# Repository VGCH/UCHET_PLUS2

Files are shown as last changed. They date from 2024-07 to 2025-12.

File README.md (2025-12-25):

## Проект устройства для интеграции счетчиков воды в системы умного дома

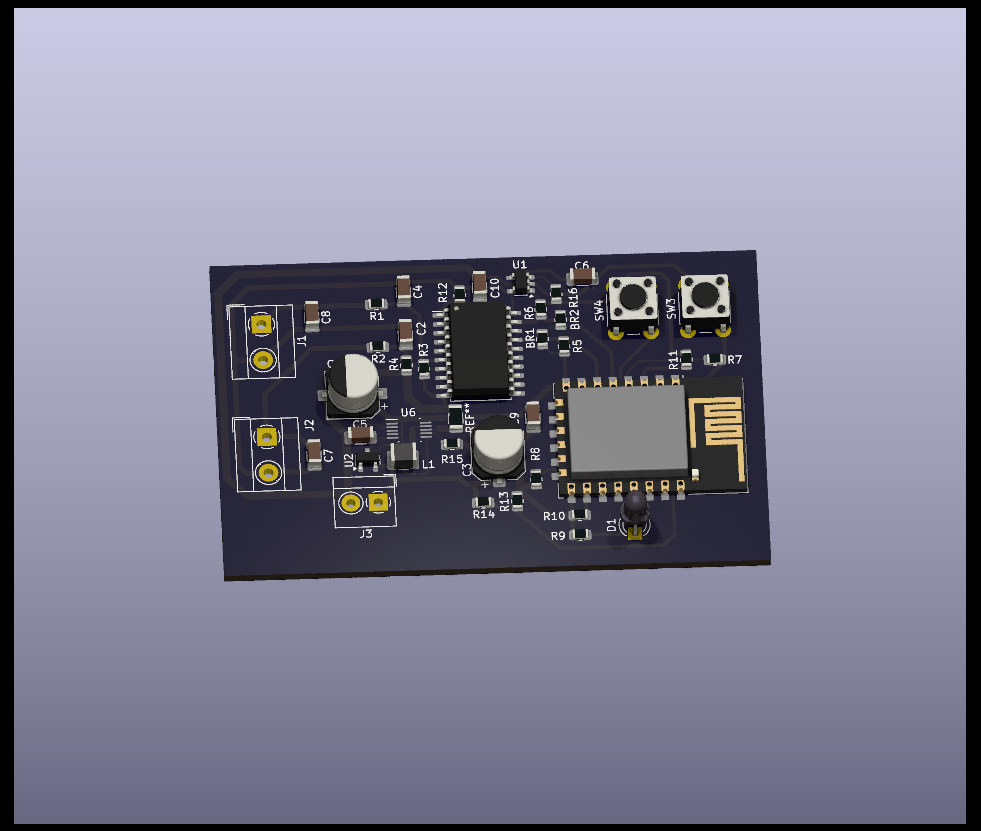
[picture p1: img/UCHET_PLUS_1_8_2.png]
Иллюстрация к проекту


Принципиальная схема

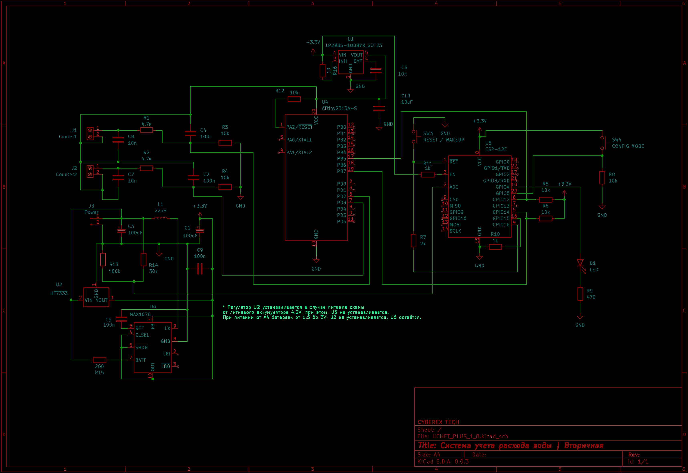
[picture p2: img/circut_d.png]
Принципиальная схема


Полное описание в статье на Хабр

[Ссылка на статью ](https://habr.com/ru/articles/827248/)

Если данный проект был вам полезен, то вы можете задонатить разработчику на оборудование. 

[Ссылка на донат](https://dalink.to/cyberex_tech)

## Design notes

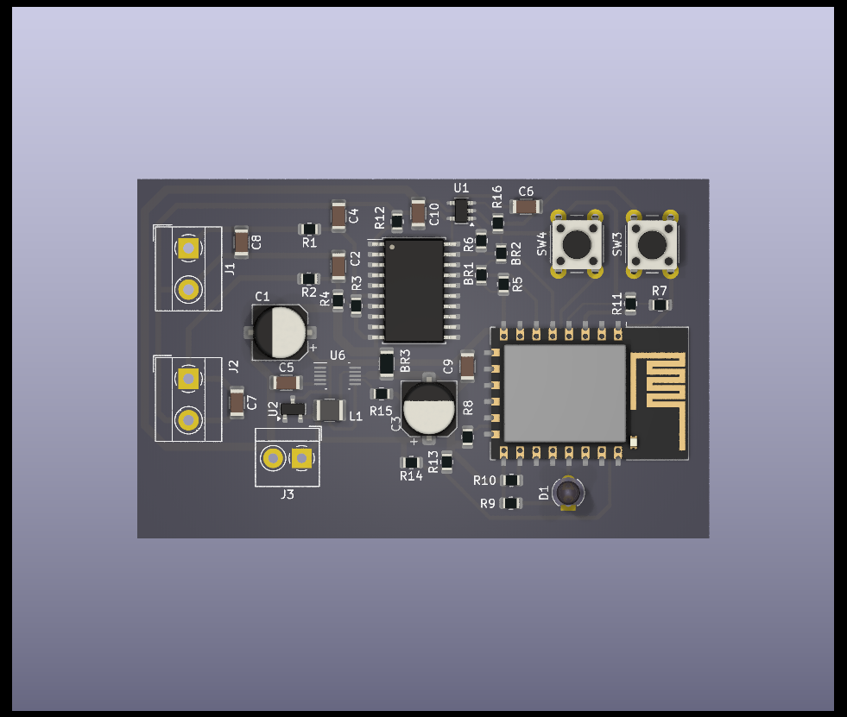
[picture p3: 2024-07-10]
img/UCHET_PLUS_1_8_3.png

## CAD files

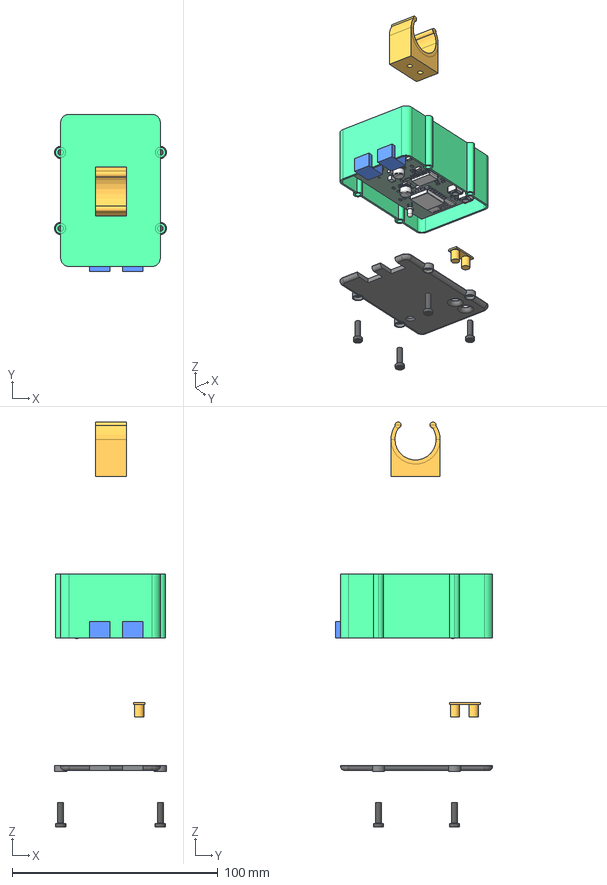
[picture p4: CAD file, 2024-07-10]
box/box_uchet_plus.FCStd
54.5 x 76.5 x 197.0 mm
Куб053
Куб054
SW_PUSH_6mm004
R_0805_2012Metric034
R_1206_3216Metric
R_0805_2012Metric036
R_0805_2012Metric038
LED_D3.0mm_IRGrey002
R_0805_2012Metric040
C_1206_3216Metric016
R_0805_2012Metric042
R_0805_2012Metric044
R_0805_2012Metric046
R_0805_2012Metric048
ESP_12E001_cp001
R_0805_2012Metric050
L_1210_3225Metric002
R_0805_2012Metric052
R_0805_2012Metric054
R_0805_2012Metric056
R_0805_2012Metric058
C_1206_3216Metric018
SOT_23_006
SW_PUSH_6mm006
C_1206_3216Metric020
CP_Elec_63x060
R_0805_2012Metric060
C_1206_3216Metric022
R_0805_2012Metric062
C_1206_3216Metric024
R_0805_2012Metric064
C_1206_3216Metric026
CP_Elec_63x061
C_1206_3216Metric028
SOIC_20W_75x128mm_P127mm001
R_0805_2012Metric066
C_1206_3216Metric030
R_0805_2012Metric068
UCHET_PLUS_1_8_PCB

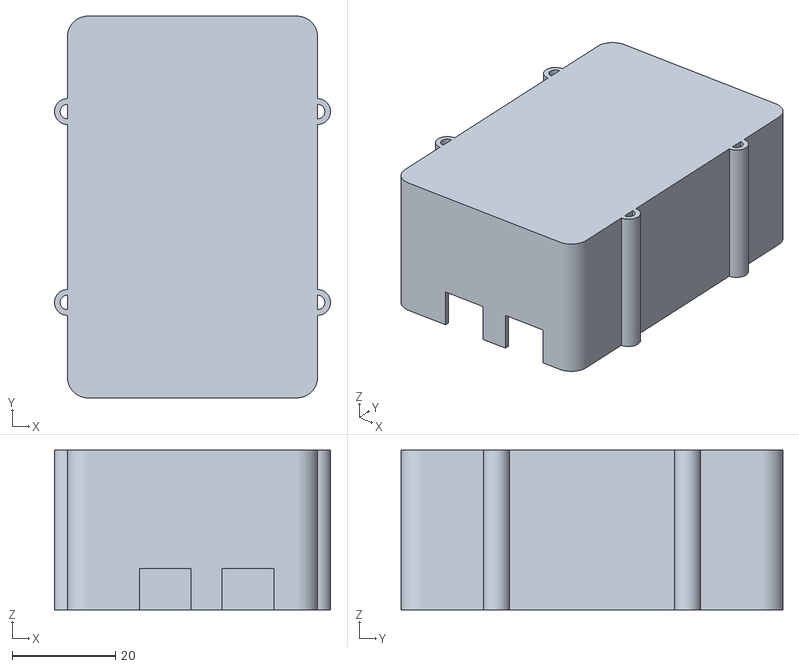
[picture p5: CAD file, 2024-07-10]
box/STL/box_uchet_plus-Cut043.stl
53.5 x 74.0 x 31.0

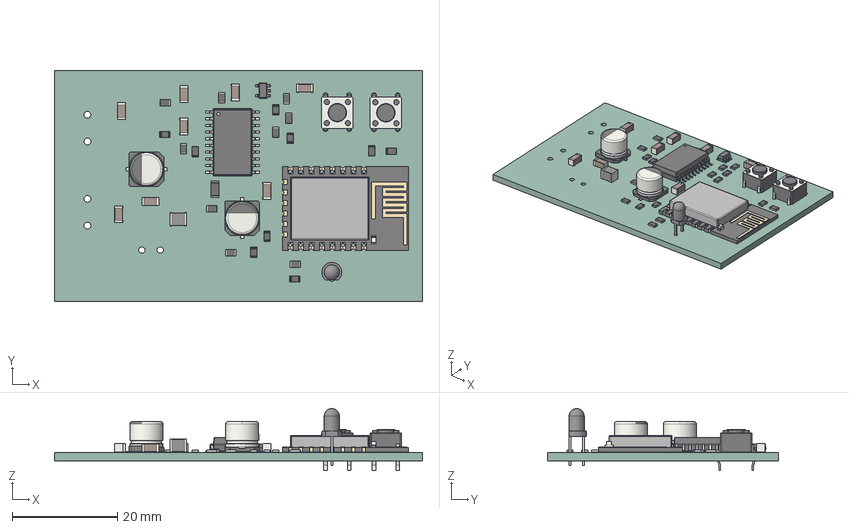
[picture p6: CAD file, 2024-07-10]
UCHET_PLUS_1_8/UCHET_PLUS_1_8.step
70.0 x 44.0 x 11.8 mm
SW_PUSH_6mm x 2
R_0805_2012Metric x 18
R_1206_3216Metric
LED_D3.0mm_IRGrey
C_1206_3216Metric x 8
ESP_12E001_cp
L_1210_3225Metric
SOT_23_5
CP_Elec_63x58 x 2
SOIC_20W_75x128mm_P127mm
UCHET_PLUS_1_8_PCB

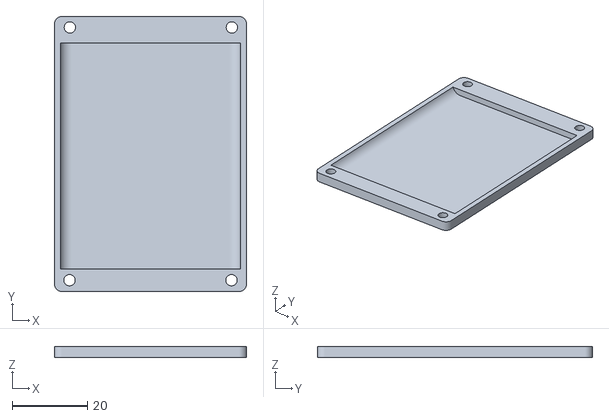
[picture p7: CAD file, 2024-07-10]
box/STL/box_uchet_plus_cup.stl
51.0 x 73.0 x 3.00

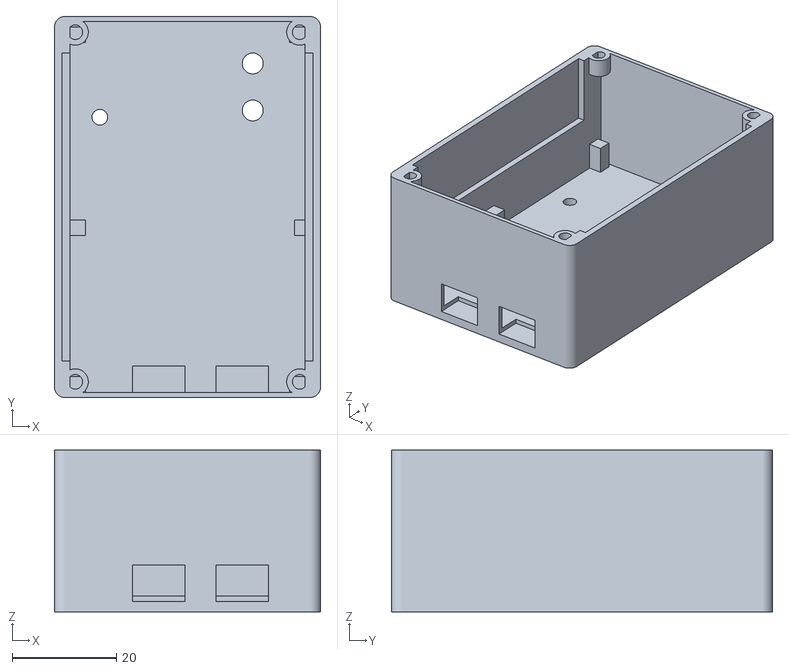
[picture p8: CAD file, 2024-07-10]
box/STL/box_uchet_plus-Cut008.stl
51.0 x 73.0 x 31.0

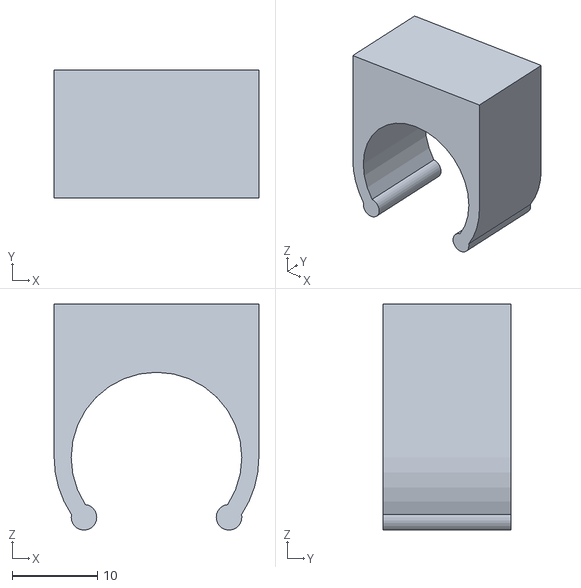
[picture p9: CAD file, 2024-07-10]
box/STL/box_uchet_plus_holder.stl
24.0 x 15.0 x 26.5

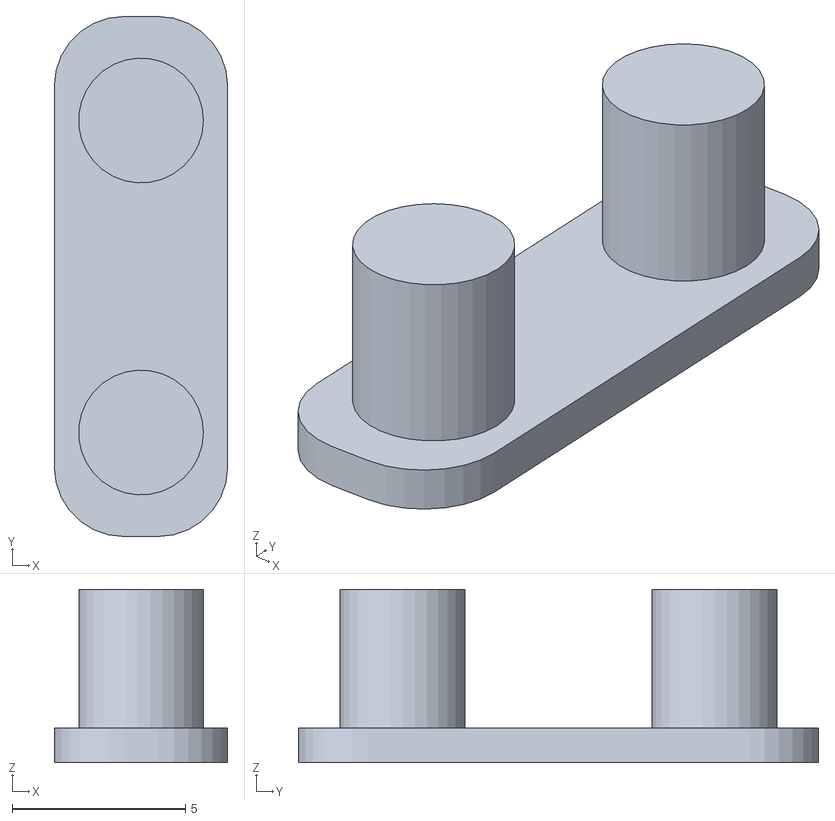
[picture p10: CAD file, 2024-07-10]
box/STL/box_uchet_but.stl
5.00 x 15.0 x 5.00

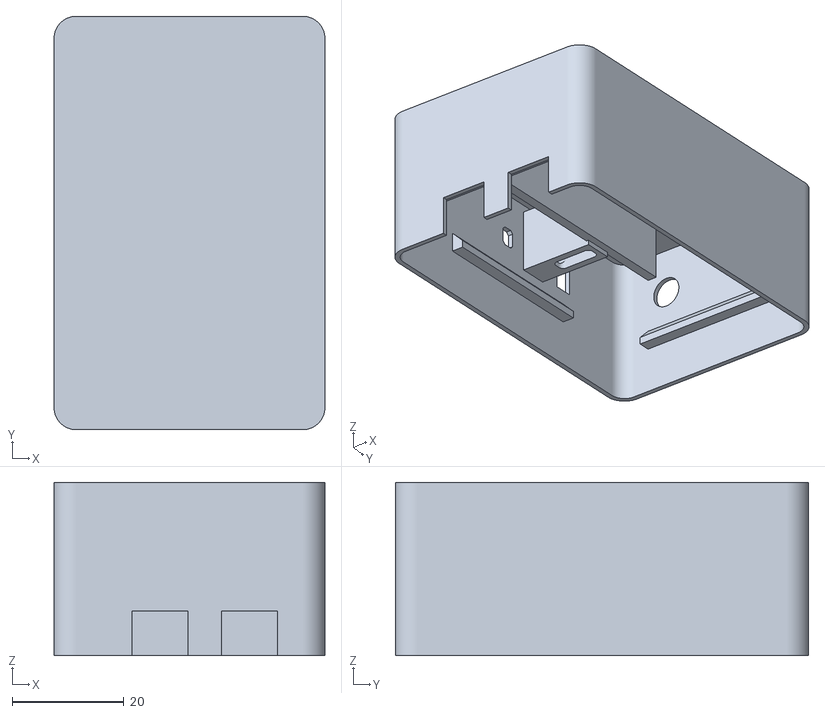
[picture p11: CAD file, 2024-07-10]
box/STL/box_uchet_plus-Fusion023.stl
48.5 x 74.0 x 31.0

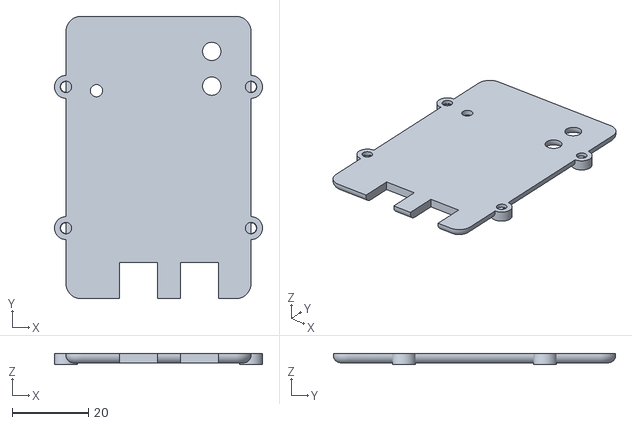
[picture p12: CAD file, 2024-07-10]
box/STL/box_uchet_plus-Cut042.stl
54.5 x 74.0 x 3.00

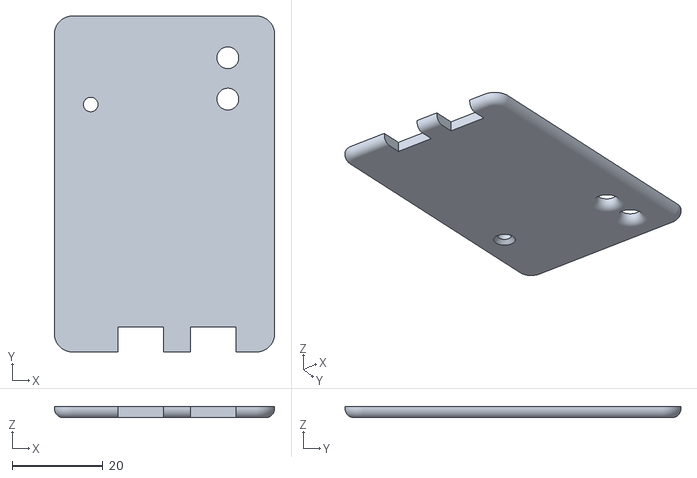
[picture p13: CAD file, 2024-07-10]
box/STL/box_uchet_plus-Cut040.stl
48.5 x 74.0 x 2.50

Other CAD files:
UCHET_PLUS_1_8/UCHET_PLUS_1_8_2.step
box/STL/box_uchet_plus-Cut044.stl
box/STL/box_uchet_plus.stl

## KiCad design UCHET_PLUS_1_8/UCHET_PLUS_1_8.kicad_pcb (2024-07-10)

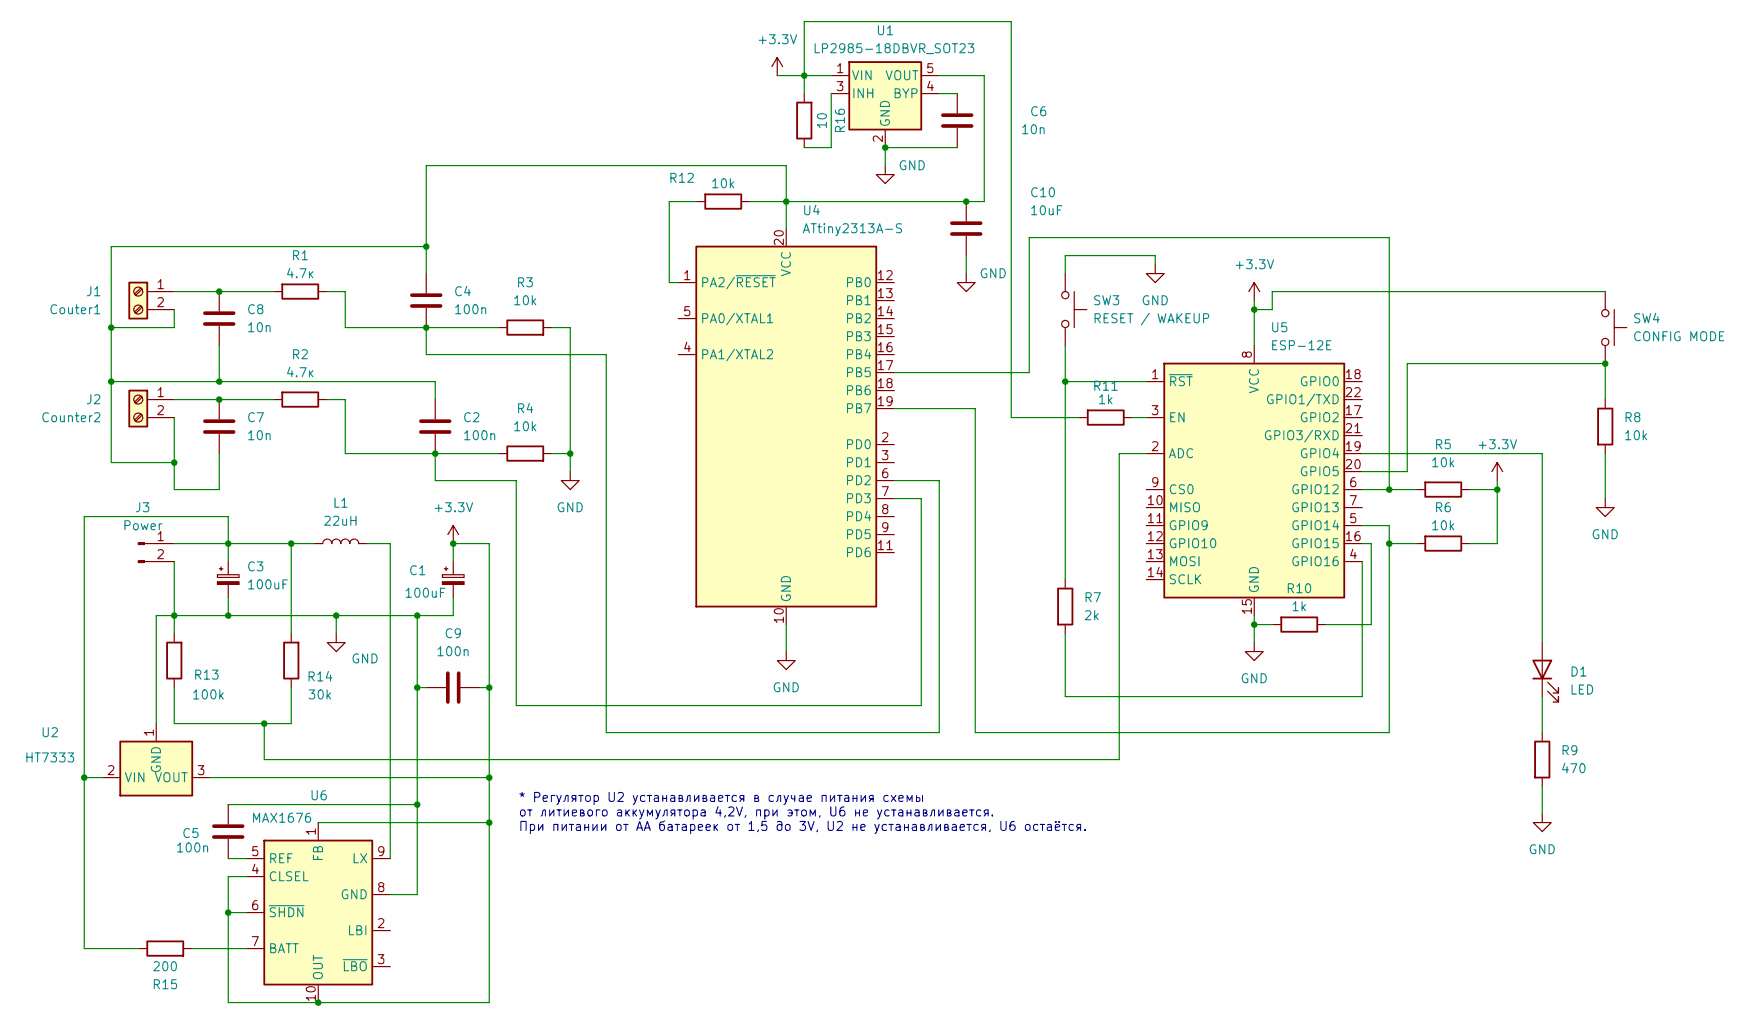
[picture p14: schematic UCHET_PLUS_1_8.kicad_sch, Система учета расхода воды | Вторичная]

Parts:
C1, C3: 100uF; CP_Elec_6.3x5.8
C2, C4, C5, C9: 100n; C_1206_3216Metric
C6, C7, C8: 10n; C_1206_3216Metric
C10: 10uF; C_1206_3216Metric
D1: LED; LED_D3.0mm_IRGrey
J1: Couter1; TerminalBlock_MetzConnect_Type101_RT01602HBWC_1x02_P5.08mm_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
J2: Counter2; TerminalBlock_MetzConnect_Type101_RT01602HBWC_1x02_P5.08mm_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
J3: Power; TerminalBlock_4Ucon_1x02_P3.50mm_Horizontal
L1: 22uH; L_1210_3225Metric
R1, R2: 4.7к; R_0805_2012Metric
R3, R4, R5, R6, R8, R12: 10k; R_0805_2012Metric
R7: 2k; R_0805_2012Metric
R9: 470; R_0805_2012Metric
R10, R11: 1k; R_0805_2012Metric
R13: 100k; R_0805_2012Metric
R14: 30k; R_0805_2012Metric
R15: 200; R_0805_2012Metric
R16: 10; R_0805_2012Metric
SW3: RESET / WAKEUP; SW_PUSH_6mm
SW4: CONFIG MODE; SW_PUSH_6mm
U1: LP2985-18DBVR_SOT23; SOT-23-5
U2: HT7333; SOT-23
U4: ATtiny2313A-S; SOIC-20W_7.5x12.8mm_P1.27mm
U5: ESP-12E
U6: MAX1676; MSOP-10-1EP_3x3mm_P0.5mm_EP2.2x3.1mm_Mask1.83x1.89mm_Therma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

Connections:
+3.3V: C1.1, C9.1, R5.1, R6.1, R11.2, R16.2, SW4.1, U1.1 (VIN), U2.3 (VOUT), U5.8 (VCC), U6.1 (FB), U6.4 (CLSEL), U6.6 (~SHDN), U6.10 (OUT), U6.11 (GND); also elsewhere on the board
GND: C1.2, C3.2, C5.1, C6.2, C9.2, C10.2, J3.2, R3.2, R4.2, R8.2, R9.2, R10.2, R13.2, SW3.1, U1.2 (GND), U2.1 (GND), U4.10 (GND), U5.15 (GND), U6.8 (GND); also elsewhere on the board
unnamed: D1.2 (A), U5.19 (GPIO4)
unnamed: D1.1 (K), R9.1
unnamed: C8.1, J1.1, R1.2
unnamed: C2.1, C4.1, C7.2, C8.2, C10.1, J1.2, J2.2, R12.1, U1.5 (VOUT), U4.20 (VCC)
unnamed: C7.1, J2.1, R2.2
unnamed: C3.1, J3.1, L1.1, R14.2, R15.1, U2.2 (VIN)
unnamed: C6.1, U1.4 (BYP)
unnamed: R16.1, U1.3 (INH)
unnamed: R12.2, U4.1 (PA2/~RESET)
unnamed: R5.2, U4.17 (PB5), U5.6 (GPIO12)
unnamed: R6.2, U4.19 (PB7), U5.5 (GPIO14)
unnamed: C4.2, R1.1, R3.1, U4.6 (PD2)
unnamed: C2.2, R2.1, R4.1, U4.7 (PD3)
unnamed: R13.1, R14.1, U5.2 (ADC)
unnamed: R11.1, U5.3 (EN)
unnamed: R8.1, SW4.2, U5.20 (GPIO5)
unnamed: R10.1, U5.16 (GPIO15)
unnamed: R7.2, U5.4 (GPIO16)
unnamed: R7.1, SW3.2, U5.1 (~RST)
unnamed: R15.2, U6.7 (BATT)
unnamed: L1.2, U6.9 (LX)
unnamed: C5.2, U6.5 (REF)

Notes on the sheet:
* Регулятор U2 устанавливается в случае питания схемы от литиевого аккумулятора 4,2V, при этом, U6 не устанавливается. При питании от AA батареек от 1,5 до 3V, U2 не устанавливается, U6 остаётся.

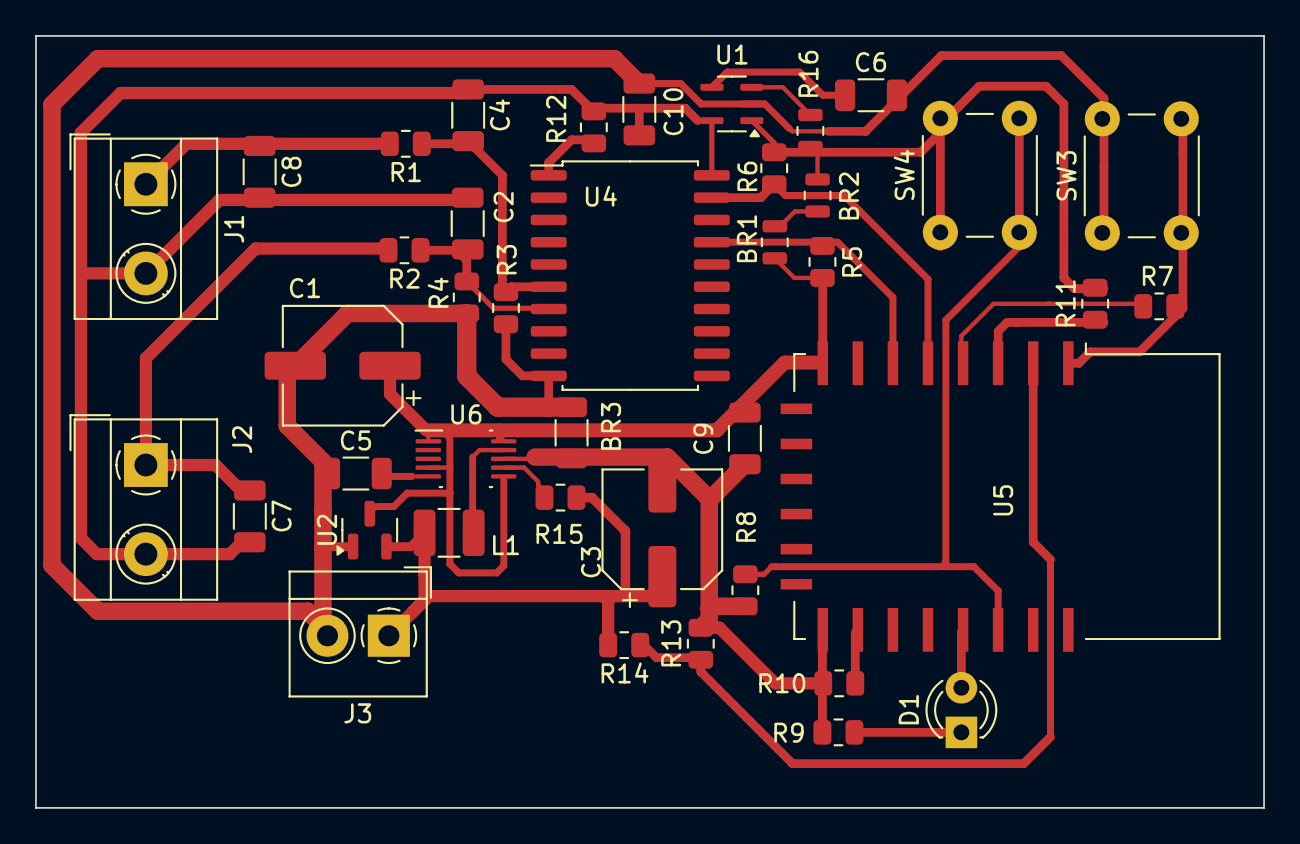
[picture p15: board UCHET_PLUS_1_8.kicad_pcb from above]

Board: 2 copper layers, 70.0 x 44.0 mm, 41 parts (0 on the bottom side), 24 nets.

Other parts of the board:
BR1, BR2: R_0805_2012Metric
BR3: R_1206_3216Metric

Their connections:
+3.3V: BR1.1, BR1.2, BR2.1, BR2.2; also elsewhere on the board
GND: BR3.1, BR3.2; also elsewhere on the board

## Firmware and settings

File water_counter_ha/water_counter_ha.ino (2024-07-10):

/* Устройство для получения данных с водосчетчиков с батарейным питанием
 *  
 *  © CYBEREX Tech, 2023
 * 
 */

#include <ESP8266WiFi.h>
#include <WiFiClient.h>
#include <ESP8266WebServer.h>
#include <ESP8266HTTPUpdateServer.h>
#include <DNSServer.h>
#include <ESP8266mDNS.h>
#include <EEPROM.h>
#include <ESP8266SSDP.h>
#include <PubSubClient.h>
#include <Wire.h>
#include "const_js.h"

// Pins
#define STATUS_LED     4               // Индикатор статуса системы / индикация импульсов
#define CONFIG_MODE    5               // Режим восстановления доступа
#define COUNTER_ACT   13
#define SLAVE_ADDRESS 18               // Адрес счетчика на шине I2C


// WEBs
ESP8266WebServer server(80);
WiFiClient espClient;
PubSubClient client(espClient);
IPAddress apIP(10, 10, 20, 1);
IPAddress netMsk(255, 255, 255, 0);
ESP8266HTTPUpdateServer httpUpdater;

// DNS server
const byte             DNS_PORT = 53;
DNSServer              dnsServer;

// Текущий статус WLAN
unsigned int status = WL_IDLE_STATUS;

// Переменные для хранения статуса сетевого подключения
boolean stat_reboot, led_stat, stat_wifi, wi_fi_st, connect, config_st ; 

// Переменные используемые для CaptivePortal
const char *myHostname  = "Cyberex_sensors";            // Имя создаваемого хоста Cyberex_sensor.local 
const char *softAP_ssid = "CYBEREX-COUNT";              // Имя создаваемой точки доступа Wi-Fi

String version_code = "WM-1.5.12.16";

// Переменная для хранения времени последней попытки сетевого подключения
unsigned long lastConnectTry = 0;
// Другие таймеры
unsigned long reboot_t = 0;
uint32_t t10s, led;
uint32_t L_1, L_2;
uint32_t receivedCounter0_storage = 0;
uint32_t receivedCounter1_storage = 0;

int count_rf = 0;

// Структура для хранения токенов сессий 
struct Token {
    String value;
    long created;
    long lifetime;
};

Token   tokens[20];                    // Длина массива структур хранения токенов 

#define TOKEN_LIFETIME 6000000         // время жизни токена в секундах

#define MAX_STRING_LENGTH 30           // Максимальное количество символов для хранения в конфигурации


// Структура для хранения конфигурации устройства
struct {
     boolean mqtt_en;
     boolean json_en;
     int     mqtt_time;
     int     statteeprom; 
     int     counter_coeff;
     float   total;
     char    mySSID[MAX_STRING_LENGTH];
     char    myPW[MAX_STRING_LENGTH];
     char    mqtt_serv[MAX_STRING_LENGTH];
     String  mqtt_user;
     String  mqtt_passw;
     String  mqtt_id;
     String  mqtt_topic;
     String  passwd;  
     int     counter_coeff_2;
     float   total_2;  
     boolean post_en;
     char    post_token[MAX_STRING_LENGTH];
  } settings;


int  CP10s, CP1m, CP5m, CP60m;                                      // Накопление импульсов счетчика 10с/1м/5м/60м 
int  bCP10s, bCP1m, bCP5m, bCP60m;                                  // Накопление импульсов счетчика 10с/1м/5м/60м буфер
float val10s, val1m, val5m, val60m;                                 // Накопленные значения расхода 10с/1м/5м/60м 
long count_total;                                                   // Общее количество импульсов счетчика

void setup() {
    EEPROM.begin(sizeof(settings));                                 // Инициализация EEPROM в соответствии с размером структуры конфигурации    
    pinMode(STATUS_LED, OUTPUT);
    ESP.rtcUserMemoryRead(0, &receivedCounter0_storage, sizeof(receivedCounter0_storage));
    ESP.rtcUserMemoryRead(sizeof(receivedCounter0_storage), &receivedCounter1_storage, sizeof(receivedCounter1_storage));
    Wire.pins(12, 14);                                              // устанавливаем пины SDA,SCL для i2c  
    Wire.begin();                                                   // Инициализируем шину I2C  SDA 12 --> 17  SCL 14 --> 19
    read_config();                                                  // Чтение конфигурации из EEPROM
    check_clean();                                                  // Провека на запуск устройства после первичной прошивки
     if(String(settings.passwd) == ""){   
        settings.passwd = "admin";                                  // Если  переменная settings.passwd пуста, то назначаем пароль по умолчанию
     }             
     WiFi.mode(WIFI_STA);                                           // Выбираем режим клиента для сетевого подключения по Wi-Fi  
     WiFi.hostname("Water-Meter [CYBEREX TECH]");                   // Указываеем имя хоста, который будет отображаться в Wi-Fi роутере, при подключении устройства
     if(WiFi.status() != WL_CONNECTED) {                            // Инициализируем подключение, если устройство ещё не подключено к сети
           WiFi.begin(settings.mySSID, settings.myPW);
      }

     for(int x = 0; x < 60; x ++){                                  // Цикл ожидания подключения к сети (30 сек)
          if (WiFi.status() == WL_CONNECTED){ 
                digitalWrite(STATUS_LED, LOW);
                stat_wifi = true;
                break;
           }
               digitalWrite(STATUS_LED, !digitalRead(STATUS_LED));     // Мигаем светодиодом в процессе ожидания подключения
               delay(500); 
      
          }

     if(WiFi.status() != WL_CONNECTED) {                             // Если подключение не удалось, то запускаем режим точки доступа Wi-Fi для конфигурации устройства
            WiFi.mode(WIFI_AP_STA);
            WiFi.softAPConfig(apIP, apIP, netMsk);
            WiFi.softAP(softAP_ssid);
            digitalWrite(STATUS_LED,  HIGH);
            stat_wifi = false;
        }
        
        delay(2000);
        if(digitalRead(CONFIG_MODE)){
           config_st = true;
        // Запускаем DNS сервер
        dnsServer.setErrorReplyCode(DNSReplyCode::NoError);
        dnsServer.start(DNS_PORT, "*", apIP);
        // WEB страницы
        server.on("/", page_process);
        server.on("/login", handleLogin);
        server.on("/script.js", reboot_devsend);
        server.on("/style.css", css);
        server.on("/index.html", HTTP_GET, [](){
        server.send(200, "text/plain", "IoT Radiation Sensor"); });
        server.on("/description.xml", HTTP_GET, [](){SSDP.schema(server.client());});
        server.on("/inline", []() {
        server.send(200, "text/plain", "this works without need of authentification");
        });
        server.onNotFound(handleNotFound);
        const char * headerkeys[] = {"User-Agent", "Cookie"} ;               // Здесь список заголовков для записи
        size_t headerkeyssize = sizeof(headerkeys) / sizeof(char*);
        server.collectHeaders(headerkeys, headerkeyssize);                   // Запускаем на сервере отслеживание заголовков 
        server.begin();
        connect = strlen(settings.mySSID) > 0;                               // Статус подключения к Wi-Fi сети, если есть имя сети
        SSDP_init();
        }else{
              digitalWrite(STATUS_LED,  HIGH);
              if(stat_wifi){
                 read_count();
                 post_send();
              }
              digitalWrite(STATUS_LED,  LOW);
              delay(5000);
              ESP.deepSleep((uint32_t)(settings.mqtt_time * 60e6));
        }
       
}

void loop() {
        portals();
        dnsServer.processNextRequest();
        server.handleClient();  
        led_ind();
        timers();
        reboot_dev_delay();
        //MQTT_send();
        if(millis() > 900000){
            ESP.deepSleep((uint32_t)(settings.mqtt_time * 60e6));
        }
}

void reboot_devsend(){
   server.send(200, "text", reb_d);
}

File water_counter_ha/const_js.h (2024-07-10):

const char reb_d[] = R"rawliteral(
   function rebootdev() {
        modal.style.display = "block";
     }
   var t = 60;
   var time = document.getElementsByClassName("clock")[0];
     function fun() {
         t--;
        time.innerHTML = "<b>Оставшееся время: "+ t +" сек.</b>"
       if(t <= 0) {
         location.href = "/";
         clearInterval(inter);
       }
   }
   
  function rebootdev_s() {
      var msg = document.getElementsByClassName("modal-body")[0];
      var req5 = new XMLHttpRequest();
            req5.open('GET','/?page=dev_reboot');
            req5.onreadystatechange = function(){
              if (req5.readyState === 4 && req5.status === 200) {
                     msg.innerHTML ="<br><b>Выполняется перезапуск устройства...</b><br>"
                     var inter = setInterval("fun()", 1000);
              }
            }
        req5.send();
})rawliteral";

//=========================================

const char html[] = R"(
                  body {
                  background: linear-gradient(to bottom, #060345, #023f78, #540110, #013a42, #1f3d6e);
                    }
                  form {
                       margin: 20px auto 0;
                       max-width: 500px;
                       padding: 10px;
                       border-radius: 10px;
                       background-color: #fff;
                    }
                  div#response2, div#response21, div#response3 {
                       margin: 10px auto 0;
                       max-width: 500px;
                       padding: 20px;
                       border-radius: 10px;
                       background: linear-gradient(to bottom right, #9df3f5, #e6e8e7);
                    }
                    label {
                        display: block;
                        color: #5769a1;
                        margin: 10px;
                    }
                  input[type=text], input[type=password], input[type=number], input[type=file], select {
                        width: 100%;
                        padding: 10px;
                        margin-bottom: 5px;
                        border: 1px solid #ccc;
                        border-radius: 4px;
                        box-sizing: border-box;
                      }
                     input[type=submit] {
                        background-color: #3482f7;
                        color: white;
                        padding: 12px 20px;
                        border: none;
                        border-radius: 4px;
                        cursor: pointer;
                     }
                    h2 {
                        text-align: center;
                        margin-top: 10px;
                        font-size: 30px;
                        color: white;
                    }
                    text {
                       text-align: left;
                       margin-top: 5px;
                       font-size: 15px;
                       font-family: Arial;
                       color: #01302b;
                     }
                    div.live {
                       text-align: right;
                       margin-top: 0px;
                       font-size: 30px;
                       font-family: Arial;
                       color: #066094;
                     }
                     div.livePM {
                       text-align: right;
                       margin-top: 0px;
                       font-size: 35px;
                       font-family: Monotype Corsiva;
                       color: #800404;
                     }
                    div.modal {
                       text-align: left;
                       margin-top: 0px;
                       font-size: 30px;
                       color: #066094;
                     }
                      a {
                       text-align: center;
                       margin-top: 0px;
                       font-size: 16px;
                       text-decoration: none;
                       color: #9ee8e8;
                     }
                     a.mod {
                       text-align: center;
                       margin-top: 0px;
                       font-size: 18px;
                       text-decoration: none;
                       color: #3e5d80;
                     }
                    .spoiler input, .spoiler div  { 
                        display: none; 
                     }
                    .spoiler :checked ~ div {
                     display: block;
                     }
                     footer {
                       text-align: center;
                       margin-top: 10px;
                       font-size: 15px;
                       color: #cbd6f2;
                     }
                      #myBtn {                     
                      background-color: #9C27B0;  
                      color: white; 
                      padding: 12px 16px;
                      font-size: 18px;
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

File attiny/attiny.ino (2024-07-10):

#include <Wire.h>

int32_t  counter0 = 0;
int32_t  counter1 = 0;
uint16_t data = 0;
uint16_t data_t;

void setup() {
  pinMode(4, INPUT_PULLUP);                  // Пин счетчика 1
  pinMode(5, INPUT_PULLUP);                  // Пин счетчика 2


  attachInterrupt(0, countPulses0, FALLING); // Прерывание на INT0 при падении сигнала
  attachInterrupt(1, countPulses1, FALLING); // Прерывание на INT1 при падении сигнала

  Wire.begin(18);                            // Устанавливаем адрес устройства I2C
  //PB5: SDA (Serial Data)  - 12
  //PB7: SCL (Serial Clock) - 14
  Wire.onRequest(sendCounters);              // Устанавливаем функцию обработки запроса на передачу данных
}

void loop() {
     sender();                               // Это пустая функция в точке входа, чтобы контроллер работал, иначе не работает
}

void countPulses0() {
  counter0++;
}

void countPulses1() {
  counter1++;
}

void sender(){
  if((millis() - data_t) > data*3600000 && data >= 1 ){    // Событие которое не сработает никогда 
          data_t    = millis();
          digitalWrite(10, HIGH);
          while((data_t + 1000) > millis()){}
          digitalWrite(10, LOW);
        }

}

void sendCounters() {
    byte byteData[8];                                      // массив для хранения байтов
    byteData[0] = (counter0 >> 24) & 0xFF;                 // старший байт счетчика 0
    byteData[1] = (counter0 >> 16) & 0xFF;
    byteData[2] = (counter0 >> 8) & 0xFF;
    byteData[3] = counter0 & 0xFF;                         // младший байт счетчика 0

    byteData[4] = (counter1 >> 24) & 0xFF;                 // старший байт счетчика 1
    byteData[5] = (counter1 >> 16) & 0xFF;
    byteData[6] = (counter1 >> 8) & 0xFF;
    byteData[7] = counter1 & 0xFF;                         // младший байт счетчика 1


    Wire.write(byteData, 8);                               // Отправляем данные по шине I2C
   
   }
